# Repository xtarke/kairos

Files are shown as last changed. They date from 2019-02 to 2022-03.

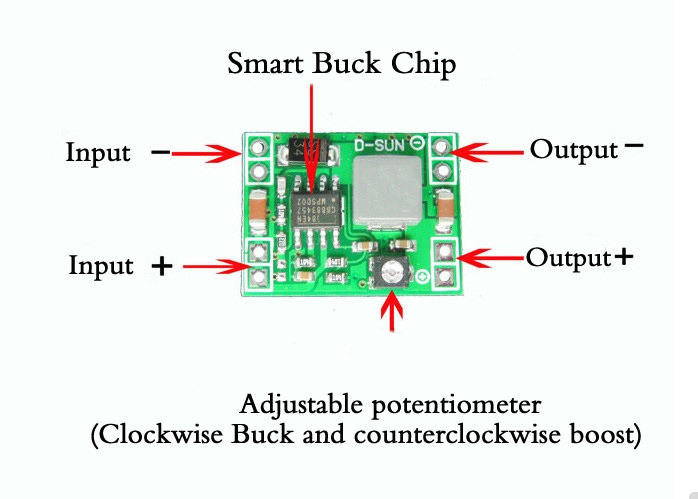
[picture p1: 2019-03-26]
hardware/v2/files/fonte_03.jpg

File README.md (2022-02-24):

# Projeto Kairos

## Tópicos

### Sensores

- temperatura0: RS485=0x0a
- temperatura1: RS485=0x0e
- temperatura2: RS485=0x0b
- temperatura3: RS485=0x0c
- pressão: 4 a 20mA

### Configuração

- tanque/xyz/cfg/0 : temperatura 0 ativado/desativado
- tanque/xyz/cfg/1 : temperatura 1 ativado/desativado
- tanque/xyz/cfg/2 : temperatura 2 ativado/desativado
- tanque/xyz/cfg/3 : temperatura 3 ativado/desativado
- tanque/xyz/cfg/4 : pressão ativado/desativado
- Configuração do fundo de escala do sensor de pressão:
    - tanque/xyz/cfg/5 : alpha (multiplicado por 1000).
    - tanque/xyz/cfg/6 : beta (multiplicado por 1000).

```
P(i) = alpha * i - beta

alpha = Full_Scale  * 1000
        ----------
           0.016

beta =  Full_Scale * 0.004       Full_Scale * 1000
        ------------------  =    -----------
            0.016                    4

P(i) = 375000*i - 1500   (0..6000 mBAR)
```

### Dados

- tanque/xyz/temperatura/0
- tanque/xyz/temperatura/1
- tanque/xyz/temperatura/2
- tanque/xyz/temperatura/3
- tanque/xyz/pressao

## Guia de instalação banco de dados temporal

- Instalar InfluxDB
- Instalar Grafana [GrafanaInstall](https://grafana.com/grafana/download?platform=arm)
- Instalar Python3 Influx: ```pip3 install influxdb --user```
- Instalar paho-mqtt: ```pip3 install paho-mqtt --user```

### Configurar InfluxDB

Maiores detalhes  em [InfluxManual](https://docs.influxdata.com/influxdb/v1.7/administration/authentication_and_authorization/#authorization)

- Criação usuário _admin_:
```
CREATE USER admin WITH PASSWORD '<password>' WITH ALL PRIVILEGES
```

- Influx desabilita usuários por padrão, portanto altere a configuração de _/etc/influxdb/influxdb.conf_ para:
```
[http]
  enabled = true
  bind-address = ":8086"
  auth-enabled = true #<--------------
  log-enabled = true
  write-tracing = false
  pprof-enabled = false
  https-enabled = true
  https-certificate = "/etc/ssl/influxdb.pem"
```

- Criação usuário _xyz_:
```
    CREATE USER xyz WITH PASSWORD '123456'
```

- Conexão a partir desse momento exige usuário e senha:

```
    influx -username admin -password <senha>
```

- Criação do banco de dados:

```
    CREATE DATABASE "myDB"
```

- Criação do banco de dados com duração de 1 dia e replicação igual a 1 [Database Mangement](https://docs.influxdata.com/influxdb/v1.7/query_language/database_management/):

```
     CREATE RETENTION POLICY "one_day_only" ON "myDB" DURATION 1d REPLICATION 1
```

- Permissão de escrita/leitura para o usuário:

```
    GRANT ALL ON "database_name" TO "username"
```

## Manutenção banco de dados:

```
show databases
use <database_name>
select * from camera_temp
drop series from camera_temp

select * from "temp20-1" where "Float_value" > 1000

#See: https://stackoverflow.com/questions/39685114/delete-points-with-unwanted-field-values-from-influxdb-measurement

# Copy all valid data to a temporary measurement
SELECT * INTO metrics_clean FROM metrics WHERE cpu!=-1

# Drop existing dirty measurement
DROP measurement metrics

# Copy temporary measurement to existing measurement
SELECT * INTO metrics FROM metrics_clean

With timerange

# Copy all valid data to a temporary measurement within timerange
SELECT * INTO metrics_clean FROM metrics WHERE cpu!=-1 and time > '<start_time>' and time '<end_time>';

# Delete existing dirty data within timerange
DELETE FROM metrics WHERE time > '<start_time>' and time '<end_time>';

# Copy temporary measurement to existing measurement
SELECT * INTO metrics FROM metrics_clean

```

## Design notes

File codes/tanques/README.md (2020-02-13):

# Aplicação desenvolvida com ESP 8266 RTOS SDK (idf)

- ESP touch para configuração da WIFI
- menuconfig:
    - configuração do host name
    - endereço do Broker MQTT
- Logs no UART 1, baudrate 115200
- Habilitação do sensores:
    - Nos 10s incicais ao boot (9600 baudrate):
        - 'w' para reset do wifi
        - '0' liga/desliga sensor 0
        - '1' liga/desliga sensor 1
        - '2' liga/desliga sensor 2
        - '3' liga/desliga sensor 3
        - 'p' liga/desliga sensor de pressão

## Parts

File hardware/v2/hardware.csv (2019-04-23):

Id | Designator | Package | Quantity | Designation | Supplier and ref
1 | U1 | D1_mini_board | 1 | WeMos_mini
2 | J4 | BarrelJack_Horizontal | 1 | Barrel_Jack_Switch
3 | D2 | SOT-23 | 1 | BAT54S
4 | C5,C1,C2,C4,C6 | C_0805_2012Metric_Pad1.15x1.40mm_HandSolder | 5 | 100n
5 | C3 | C_1206_3216Metric_Pad1.42x1.75mm_HandSolder | 1 | 2.2u
6 | D1 | LED_D5.0mm | 1 | LED
7 | Q0,Q1,Q2 | SOT-23 | 3 | 2n7002
8 | R0,R1,R2,R3,R4,R5,R11 | R_0805_2012Metric_Pad1.15x1.40mm_HandSolder | 7 | 2k2
9 | J2,J5,J6,J7 | PinHeader_1x02_P2.54mm_Vertical | 4 | Screw_Terminal_01x02
10 | D3 | D_SMB | 1 | DIODE
11 | J3,J1 | TerminalBlock_bornier-3_P5.08mm | 2 | Screw_Terminal_1x03
12 | P1 | PinHeader_1x02_P2.54mm_Vertical | 1 | CONN_01X02
13 | P2 | PinHeader_1x08_P2.54mm_Vertical | 1 | CONN_01X08
14 | R6,R9 | R_Axial_DIN0207_L6.3mm_D2.5mm_P10.16mm_Horizontal | 2 | 150R
15 | R7,R8 | R_Axial_DIN0207_L6.3mm_D2.5mm_P10.16mm_Horizontal | 2 | 10R
16 | R10 | R_Axial_DIN0207_L6.3mm_D2.5mm_P10.16mm_Horizontal | 1 | 120R
17 | U2 | DIP-8_W7.62mm | 1 | 75LBC176
18 | R12,R13 | R_1206_3216Metric_Pad1.42x1.75mm_HandSolder | 2 | 10k
19 | R14,R15 | R_1206_3216Metric_Pad1.42x1.75mm_HandSolder | 2 | 20k
20 | R16,R17 | R_1206_3216Metric_Pad1.42x1.75mm_HandSolder | 2 | 680
21 | R18 | R_1206_3216Metric_Pad1.42x1.75mm_HandSolder | 1 | 0
22 | U3 | SOIC-8_3.9x4.9mm_P1.27mm | 1 | LM358

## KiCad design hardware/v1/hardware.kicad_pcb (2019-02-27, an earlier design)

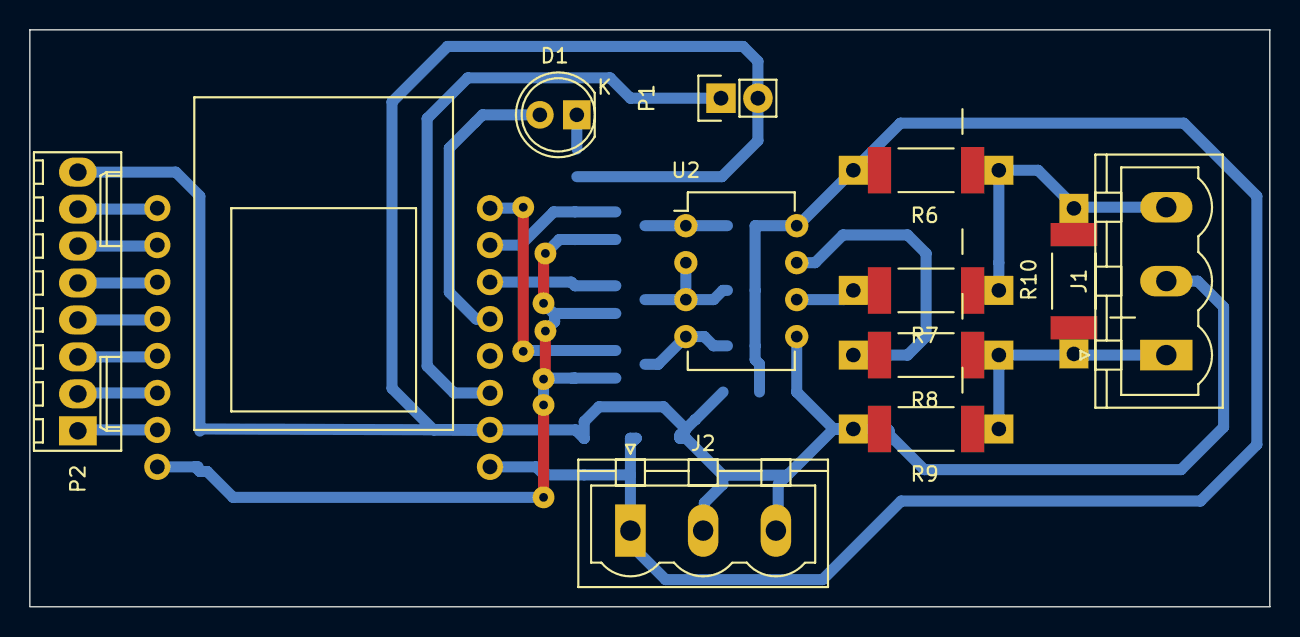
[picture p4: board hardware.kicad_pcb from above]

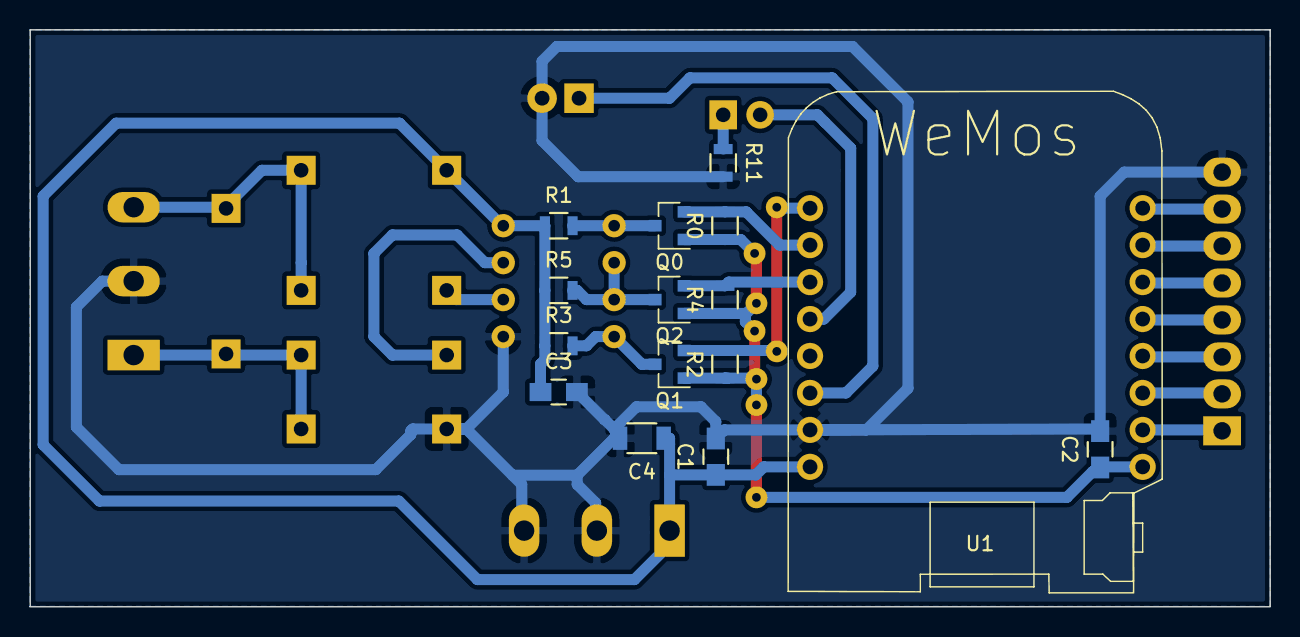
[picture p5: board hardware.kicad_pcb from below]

Board: 2 copper layers, 85.2 x 39.6 mm, 26 parts (15 on the bottom side), 23 nets.

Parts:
C1: 2.2u; C_0805_HandSoldering
C2, C3: 100n; C_0805_HandSoldering
C4: 100n; C_1206
D1: LED; LED-5MM
J1: Screw_Terminal_1x03; PhoenixContact_MSTBVA-G_03x5.08mm_Vertical
J2: Screw_Terminal_1x03; PhoenixContact_MSTBVA-G_03x5.00mm_Vertical
P1: CONN_01X02; Pin_Header_Straight_1x02
P2: CONN_01X08; Molex_KK-6410-08_08x2.54mm_Straight
Q0, Q1, Q2: 2n7002; SOT-23
R0, R1, R2, R3, R4, R5, R11: 2k2; R_0805
R6, R9: 150R; Resistor_SMD+THTuniversal_2512_RM10_HandSoldering
R7, R8: 10R; Resistor_SMD+THTuniversal_2512_RM10_HandSoldering
R10: 120R; Resistor_SMD+THTuniversal_2512_RM10_HandSoldering
U1: WeMos_mini; D1_mini_board
U2: 75LBC176; DIP-8_W7.62mm

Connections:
+3V3: C2.1, Q0.1, Q1.1, Q2.1, R0.1, R2.1, R4.1, U1.16
+5V: C1.1, C3.1, C4.1, J2.1, R1.1, R3.1, R5.1, R6.2, U1.1, U2.8
ERR_LED: D1.2, U1.5
GND: C1.2, C2.2, C3.2, C4.2, J1.2, J2.2, J2.3, P1.2, P2.8, R9.2, R11.2, U1.2, U2.5
unnamed: D1.1, R11.1
unnamed: J1.1, R8.1, R9.1, R10.1
unnamed: J1.3, R6.1, R7.1, R10.2
unnamed: P2.1, U1.15
unnamed: P2.2, U1.14
unnamed: P2.3, U1.13
unnamed: P2.4, U1.12
unnamed: P2.5, U1.11
unnamed: P2.6, U1.10
unnamed: P2.7, U1.9
unnamed: Q0.3, R1.2, U2.1
unnamed: Q1.3, R3.2, U2.4
unnamed: Q2.3, R5.2, U2.2, U2.3
unnamed: R7.2, U2.6
unnamed: R8.2, U2.7
RX: Q0.2, R0.2, U1.7
TX: Q1.2, R2.2, U1.8
TXEN: Q2.2, R4.2, U1.6
TX_DG: P1.1, U1.3

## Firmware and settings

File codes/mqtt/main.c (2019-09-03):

#include "espressif/esp_common.h"
#include "esp/uart.h"

#include <string.h>

#include <FreeRTOS.h>
#include <task.h>
#include <ssid_config.h>

#include <espressif/esp_sta.h>
#include <espressif/esp_wifi.h>

#include <paho_mqtt_c/MQTTESP8266.h>
#include <paho_mqtt_c/MQTTClient.h>

#include <semphr.h>
#include <queue.h>

#include "network.h"
#include "pressure.h"
#include "comm.h"

#include "sysparam.h"
#include "app_status.h"

// #define DEBUG

#ifdef DEBUG
#define debug(fmt, ...) printf("%s: " fmt "\n", "PWM", ## __VA_ARGS__)
#else
#define debug(fmt, ...)
#endif


static void  status_publish_task(void *pvParameters)
{
	int len;
	TickType_t xLastWakeTime = xTaskGetTickCount();

	temperature_stauts_t myData = {0,0};
    publisher_data_t to_publish_data;
    publisher_data_t to_publish_pressure;

    memset(&to_publish_pressure, 0, sizeof(to_publish_pressure));
    memset(&to_publish_data, 0, sizeof(to_publish_data));

    char *wifi_my_host_name = NULL;

	/* Get MQTT host IP from web server configuration */
	sysparam_get_string("hostname", &wifi_my_host_name);

	if (!wifi_my_host_name){
		printf("Invalid host name\n");
		strncpy(to_publish_data.topic,"host_1/temperatura/",PUB_TPC_LEN);
		strncpy(to_publish_pressure.topic,"host_1/pressao/",PUB_TPC_LEN);
	}
	else {
		strncpy(to_publish_data.topic, wifi_my_host_name,PUB_TPC_LEN);
		strncpy(to_publish_pressure.topic, wifi_my_host_name,PUB_TPC_LEN);
		free(wifi_my_host_name);
		strncat(to_publish_data.topic,"/temperatura/0",PUB_TPC_LEN);
		strncat(to_publish_pressure.topic,"/pressao",PUB_TPC_LEN);
	}


    while (1) {
        vTaskDelayUntil(&xLastWakeTime, 10000 / portTICK_PERIOD_MS);

        if (is_pressure_enable()){
		
			uint32_t pressure = get_pressure();
        	uint8_t error = get_pressure_error();

        	snprintf(to_publish_pressure.data, PUB_MSG_LEN, "%d.%d;%d", pressure/1000, pressure%1000, error);
		
        	if (xQueueSend(publish_queue, (void *)&to_publish_pressure, 0) == pdFALSE) {
        		debug("Publish queue overflow.\r\n");
        	}
		}

        for (int i=0; i < MAX_485_SENSORS; i++){

        	if (get_enable(i)) {
        		len = strnlen(to_publish_data.topic, PUB_TPC_LEN);
        		to_publish_data.topic[len-1] = '0' + i;

        		get_temperature(i, &myData);

        		int fraction = myData.temperature % 10;
        		if (fraction < 0)
        			fraction = -fraction;

				snprintf(to_publish_data.data, PUB_MSG_LEN, "%d.%d;%d", myData.temperature/10, fraction, myData.error);

				if (xQueueSend(publish_queue, (void *)&to_publish_data, 0) == pdFALSE) {
					debug("Publish queue overflow.\r\n");
				}
				vTaskDelayUntil(&xLastWakeTime, 1000 / portTICK_PERIOD_MS);
        	}
        }
    }
}

static void  hearbeat_task(void *pvParameters)
{
	GPIO.ENABLE_OUT_SET = BIT(4);
	IOMUX_GPIO4 = IOMUX_GPIO4_FUNC_GPIO | IOMUX_PIN_OUTPUT_ENABLE; /* change this line if you change 'gpio' */

	while(1) {
		/* Disable SoftAP mode if connected */
		if (sdk_wifi_station_get_connect_status() == STATION_GOT_IP){
			sdk_wifi_set_opmode(STATION_MODE);

			GPIO.OUT_SET = BIT(4);
			vTaskDelay(1000 / portTICK_PERIOD_MS);
			GPIO.OUT_CLEAR = BIT(4);
			vTaskDelay(1000 / portTICK_PERIOD_MS);
		}
		else {
			GPIO.OUT_SET = BIT(4);
			vTaskDelay(200 / portTICK_PERIOD_MS);
			GPIO.OUT_CLEAR = BIT(4);
			vTaskDelay(200 / portTICK_PERIOD_MS);
		}

	}
}

void user_init(void)
{
    uart_set_baud(0, 9600);
    uart_set_baud(1, 9600);

    /* Activate UART 1 PIN: NodeMCU's LED is the same GPIO (2 or D4) */
    gpio_set_iomux_function(2, IOMUX_GPIO2_FUNC_UART1_TXD);

    printf("SDK version:%s\n", sdk_system_get_sdk_version());

    publish_queue = xQueueCreate(8, sizeof(publisher_data_t));
    command_queue = xQueueCreate(4, sizeof(command_data_t));

    wifi_cfg();

    app_status_init();
    comm_init();

    /* To Do:
     *
     * Get return of xTaskCreate.
     *
     */
    xTaskCreate(&hearbeat_task, "led_task",  256, NULL, 3, NULL);

    xTaskCreate(&status_task, "tank_status_task", 256, NULL, 4, NULL);

    xTaskCreate(&commands_task, "485_cmd_task", 256, NULL, 4, &xHandling_485_cmd_task);

    xTaskCreate(&adc_task, "adc_task", 256, NULL, 4, NULL);
    xTaskCreate(&pressure_task, "pressure_task", 256, NULL, 4, NULL);

    xTaskCreate(&status_publish_task, "status_publish_task", 512, NULL, 6, NULL);
    xTaskCreate(&mqtt_task, "mqtt_task", 1024, NULL, 7, NULL);
}

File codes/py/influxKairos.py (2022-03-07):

#!/usr/bin/env python3

from influxdb import InfluxDBClient
import paho.mqtt.client as mqtt
import time
import logging
import argparse

logFilename = '/home/pi/influxKairos-' + time.strftime('%Y%m%d-%H-%M-%S') + '.log'
logging.basicConfig(filename=logFilename,level=logging.INFO)

class Data:
    """Class for storing MQQT data with timestamp"""
    def __init__(self, database, cloud_broker):
        self.broker = cloud_broker
        self.database = database
        self.timestamp = 0
        self.dbdata = [
        {
            "measurement": "temp",
            "tags": {
                "region": "florianopolis"
            },
            "fields": {
                "Float_value": 0.0,
                "error": 0
            }
        }
    ]

    def add_value(self, data, error):
        self.dbdata[0]['fields']['Float_value'] = data
        self.dbdata[0]['fields']['error'] = error
        self.timestamp = time.time()

    def add_record(self, measurement, data, error):
        self.dbdata[0]['measurement'] = measurement
        self.dbdata[0]['fields']['Float_value'] = data
        self.dbdata[0]['fields']['error'] = error
        self.timestamp = time.time()

        self.database.write_points(self.dbdata)

        print(self.dbdata)


    def set_error(self, error):
        self.dbdata[0]['fields']['error'] = error

    def is_new(self, timestamp):
        if self.timestamp == timestamp:
            return False
        else:
            return True

def on_connect(client, userdata, flags, rc):

    logging.warning('Connected to localhost with result code: ' + str(rc) + ' ' + time.strftime('%Y-%m-%dT%H:%M:%S'))
    print('Connected to localhost with result code ' + str(rc))

    # Subscribing in on_connect() means that if we lose the connection and
    # reconnect then subscriptions will be renewed.
    # client.subscribe("$SYS/#")

    client.subscribe('tanque/#')

def on_connect_cloud(client, userdata, flags, rc):

    logging.warning('Connected to cloud with result code: ' + str(rc) + ' ' + time.strftime('%Y-%m-%dT%H:%M:%S'))
    print('Connected to cloud with result code ' + str(rc))

def on_disconnect(client, userdata, rc):
    if rc != 0:
        print('Unexpected disconnection: ' + str(rc) + ' ' + time.strftime('%Y-%m-%dT%H:%M:%S'))
        logging.warning('Unexpected disconnection: ' + str(rc) + ' ' + time.strftime('%Y-%m-%dT%H:%M:%S'))

    # client.reconnect()


def on_message(client, userdata, message):
    #global temperature# = Data()

    # Publish messages on the cloud
    ret = userdata.broker.publish(message.topic, message.payload)

    # Add values to the databse
    topic_split = str(message.topic).split('/')
    payload_split = list(message.payload.decode('ASCII'))
    data_value = (''.join(payload_split).split(';',1))

    measurement = ''.join(topic_split)
    userdata.add_record(measurement,float(data_value[0]), int(data_value[1]))

def main():

    myData = []

    timestamp = []
    timestamp.append(0)
    timestamp.append(0)
    timestamp.append(0)

    parser = argparse.ArgumentParser(description='Simple mqtt to influx gateWay')
    parser.add_argument('broker', help='Broker address')
    parser.add_argument('user', help='Broker user')
    parser.add_argument('password', help='Broker password')
    parser.add_argument('DBuser', help='InfluxDB user')
    parser.add_argument('DBpassword', help='InfluxDB password')

    options = parser.parse_args()

    print('Connecting to {} with user {}.'.format(options.broker, options.user))
    logging.info('Connecting to {} with user {}.'.format(options.broker, options.user))

    cloud_mqtt = mqtt.Client()
    cloud_mqtt.username_pw_set('juca',  'password')
    # cloud_mqtt.connect('m14.cloudmqtt.com')
    cloud_mqtt.connect('192.168.1.2')
    cloud_mqtt.on_connect = on_connect_cloud

    local_mqtt = mqtt.Client()
    local_mqtt.username_pw_set(options.user,  options.password)
    local_mqtt.connect(options.broker)
    local_mqtt.on_disconnect = on_disconnect
    local_mqtt.on_message = on_message
    local_mqtt.on_connect = on_connect

    client = InfluxDBClient('localhost', 8086, options.DBuser, options.DBpassword)
    client.switch_database('kairos')

    data = Data(client, cloud_mqtt)
    local_mqtt.user_data_set(data)

    local_mqtt.loop_start()
    cloud_mqtt.loop_start()
    
    try:
        while True:

            time.sleep(10)


    except KeyboardInterrupt:
        print('Ending...')
        local_mqtt.disconnect()
        client.close()


if __name__ == '__main__':
    main()

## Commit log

2018-10-09 Added hardware design
    [hardware.kicad_pcb, hardware.sch]
2019-02-21 Added systemd service
    [hardware.kicad_pcb, hardware.sch]
2019-02-27 Added support for 4 G101 controllers and publish 485 comm. errors.
    [hardware.kicad_pcb]
2019-03-08 Corrected error when broker disconnects. Corrected negative temperature.
2019-03-27 PCB V2
    [hardware.sch]
2019-03-28 PCB V2
    barrel JAC colocado mais proximo da borda
    [hardware.kicad_pcb]
2019-04-05 Added pressure sensor
    [hardware.kicad_pcb, hardware.sch]
2019-04-08 Added code for publish pressure information
2019-04-16 V3 hardware
    [hardware.kicad_pcb]
2019-04-23 Corrected offset and display pressure in kgfm/cm2
    [hardware.csv, hardware.kicad_pcb, hardware.sch]
2019-05-07 Added readme
    [hardware.kicad_pcb]
2019-05-21 Board texts
    [hardware.kicad_pcb, hardware.sch]
2019-06-11 Implemented handler for 485 com. error
    [comm.c, main.c]
2019-08-02 Added more broker settings to wificfg
    [main.c]
2019-08-07 Added dafault sta wifi and password
    [hardware-2019-03-13-16-43-18.sch, hardware.csv, hardware.kicad_pcb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]
2019-09-03 Added configuration to enable/disable sensors
2019-09-06 Scale of pressure sensor is now configurable
    [press_sensor.ods, press_sensor_validacao.ods]
2020-02-07 Porting aplication to official espressif SDK
    [press_sensor_validacao.ods]
2020-05-18 Try to connect forever
    [hardware-2019-03-13-16-43-18.sch, hardware.csv, hardware.kicad_pcb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]
2020-07-02 Corrected config bug. Added conf from MQTT
    [main.c]
2020-07-03 Reset wifi from network
    [main.c, wifi_esptouch.c]
2022-02-24 Adicionado TLS (mudar apenas url para mqtts://. Tempos de aquisição em 20s
